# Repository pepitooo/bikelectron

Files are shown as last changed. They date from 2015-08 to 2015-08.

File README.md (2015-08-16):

# BikElectron
Personnal project to illumate rim on a bike during night, "Tron" effect

## Why this project ?
To be simple, I was not satisfy with the common lightning system. I saw on kickstarter some project with led around the rim, but it had too much constraints and it was so visible during day. Then the idea : using "glow in the dark" stickers.

## First prototype
The [first prototype](https://github.com/pepitooo/OpenSCAD_leds_support) was not too bad, using a flashlight from DX.com or AliExpress and some glow in the dark tape.

I was not so happy with the size of each led support and fix system was not good at all.

# Project parts

## Electronic
It's so basic, 2 times a resitor and a UV/blacklight led in parallel.
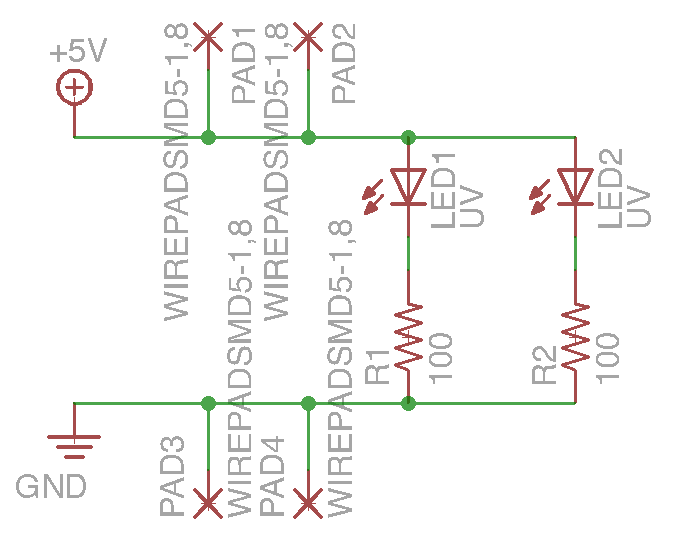
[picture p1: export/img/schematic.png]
Eagle shematic Screenshot


## PCB
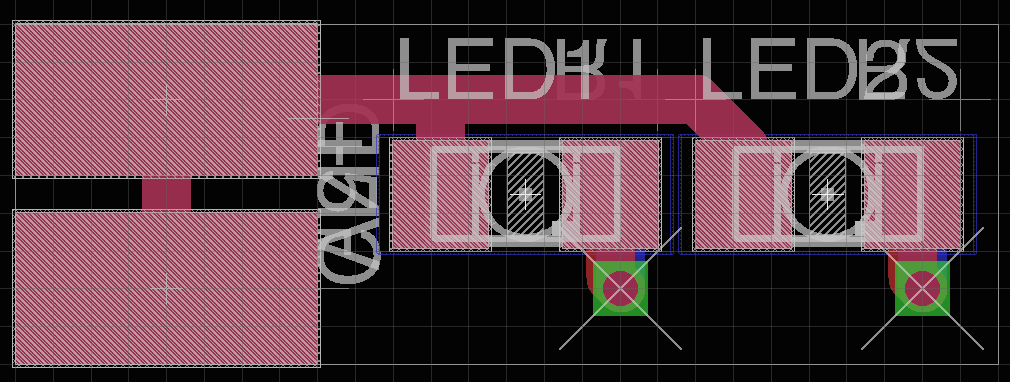
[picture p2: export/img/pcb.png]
Eagle PCB Screenshot


## Battery pack
I took a battery pack used to charge phone, it's cheap, and powerfull enough.
I used a USB cable for wiring all modules togeter.

## Case 3D printed
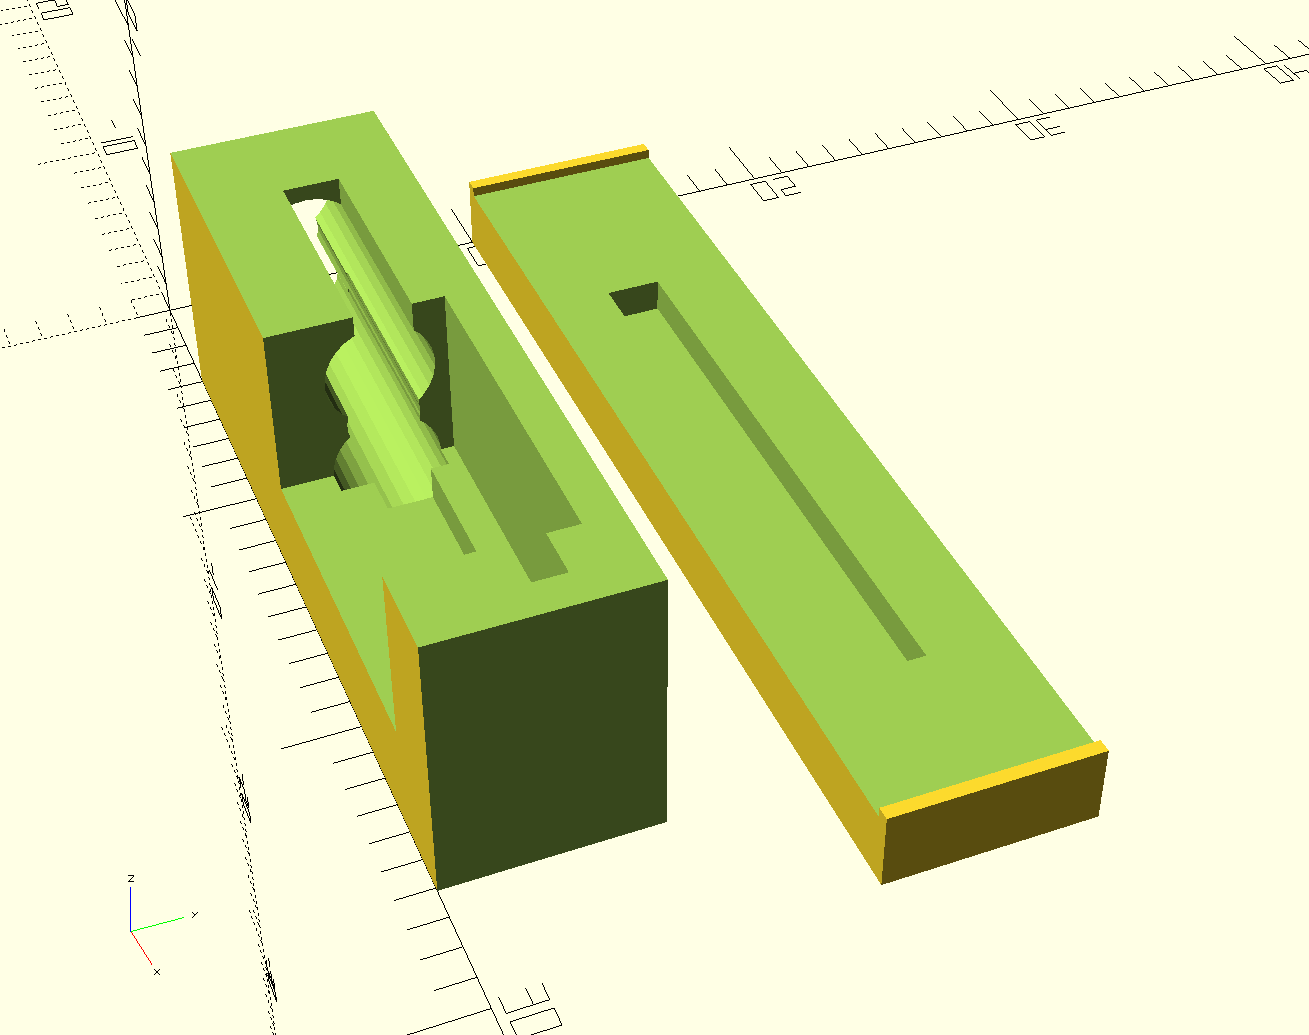
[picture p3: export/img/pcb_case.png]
Case Screenshot


## Stickers
I used glow in the dark vinyl warp and lazer cut it. If you are precise enough cisor can do the job.
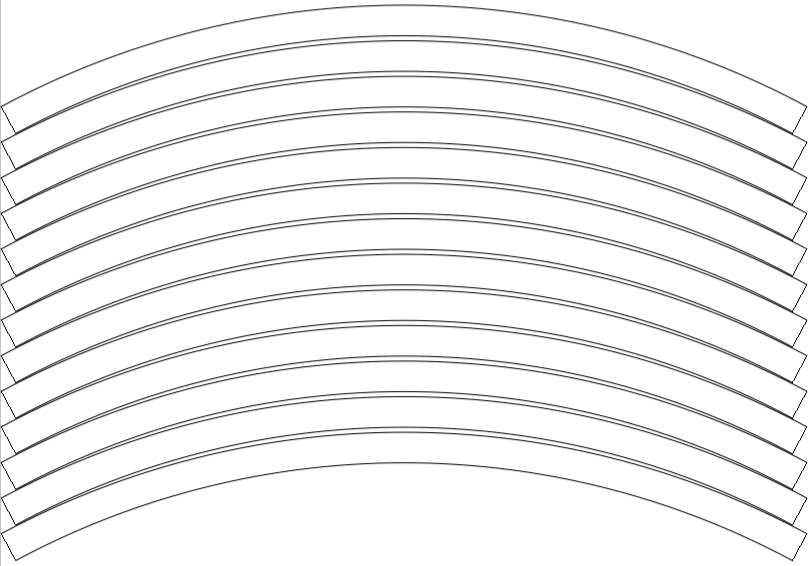
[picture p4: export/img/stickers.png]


## All elements together
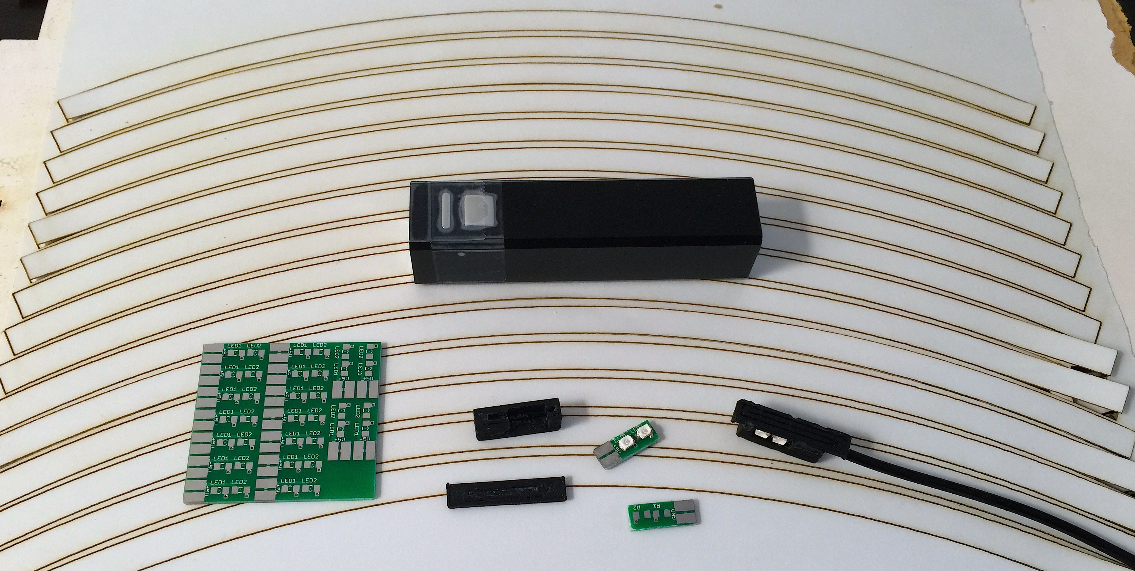
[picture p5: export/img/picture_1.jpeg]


# Final product
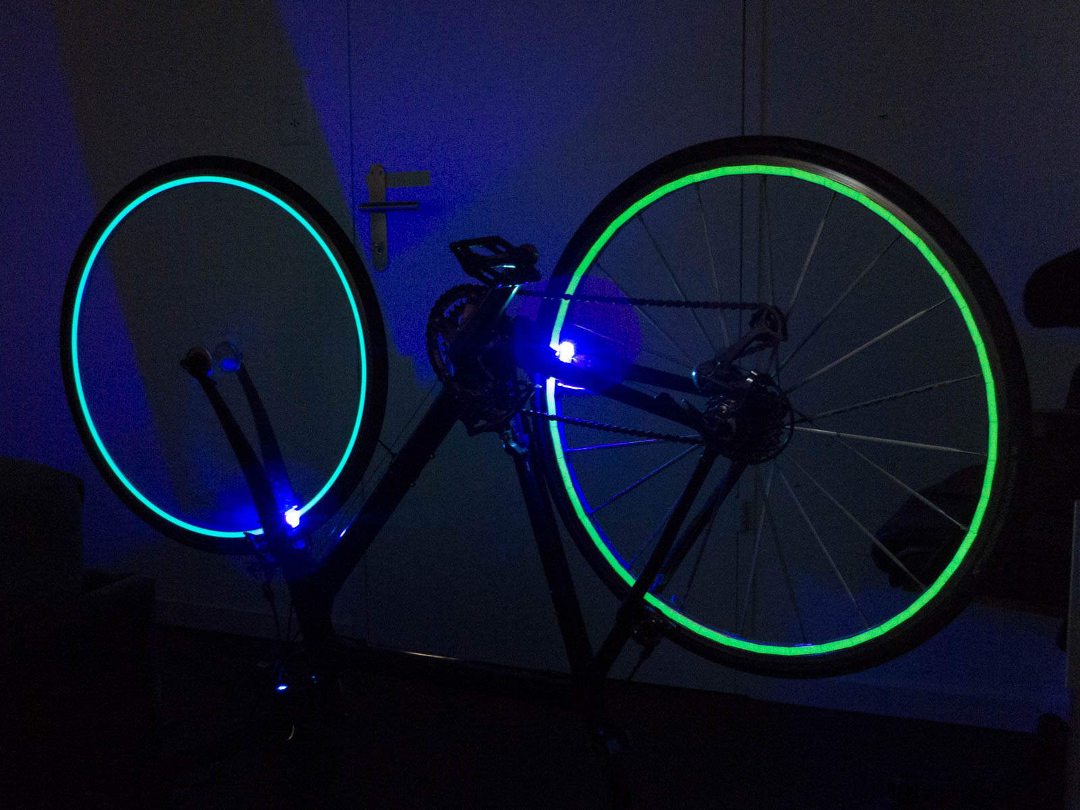
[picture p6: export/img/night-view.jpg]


You need to sold in serial 2 led module for each wheel using the USB cable.
On the picture of the final product the front wheel is more blue than rear, it's because I bought some blue glow in the dark tape. 

I used the stickers lazer cut for the front wheel, and for the rear wheel it's from the [first prototype](https://github.com/pepitooo/OpenSCAD_leds_support) where I used 10mm tape, and cut in a lot of small piece to cover all the rim.

If you want to do the same, take a good quality glow in the dark viny to have a shiny light. The chinese seller use hour of light after illumination as "quality" take one with at least 12 hours.

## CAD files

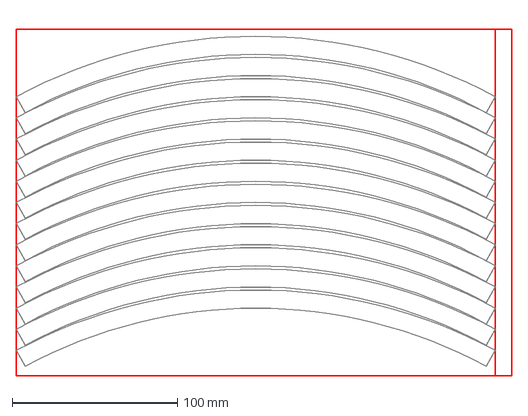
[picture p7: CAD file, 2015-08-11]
cad/stickers/stickers_rim_700c.dxf
300.0 x 217.9 mm

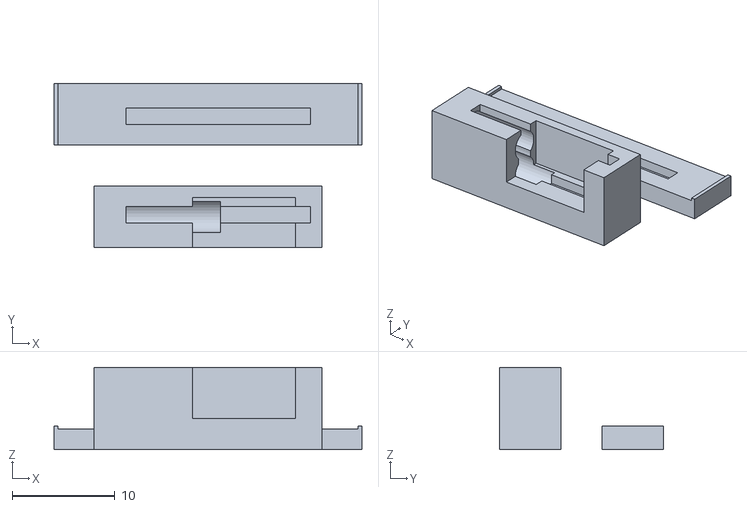
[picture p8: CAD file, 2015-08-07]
export/stl/leds_support_for_pcb_right.stl
30.0 x 16.0 x 7.99

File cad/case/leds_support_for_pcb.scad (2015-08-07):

$fn=30;

pcb_thickness=1.6;
pcb_length=18;

top_block=[30,6,10];

wire_hole_diameter=3.05;

handle_size = 4;

module resistor_1206(){
  color([1,0,0.5])
    cube([3, 0.5, 1.5], 0);
}
module led_3528(){
  color([0,0,0.5])
    translate([0, -1.9, 0])
      cube([4.5, 1.9, 2.8], 0);
}

module pcb(thickness) {
  color([0,1,0.5])
    cube([pcb_length, thickness, 7], 0);
  
  //translate([7, thickness, 3]) resistor_1206();
  //translate([12, thickness, 3]) resistor_1206();
  //translate([6.3, 0, 2]) led_3528();
  //translate([11.3, 0, 2]) led_3528();
}

module handle() {
  color([1,0.7,0.5])
    translate([30/2 - handle_size + 0.1,-0.5,0]) {
      difference() {
        cube([handle_size, 9, 10]);
        translate([3.5, 0, 0])
          cube([.5,9,.3]);
      }
    }
}

module wire_pass_through(diameter) {
  //rotate([90,270,90])
  translate([16.1,0,1])
  rotate([0,270,0]) {
    //difference() {
    //  cube([9,6,3]);
      translate([3,3,-.1])
        cylinder(h = 17, d=diameter);
      translate([6,3,-.1])
        cylinder(h = 17, d=diameter);
      translate([4.5,3,-.1])
        cylinder(h = 17, d=diameter-1);
    }
}

module led_window(leftSideWindows = false) {
  color([1,0.7,0.5])
    if(leftSideWindows) {
      translate([12.5,-.1,2])
          cube([10,5,5]);
    } else {
      translate([13.5,1.1,2])
          cube([10,5,5]);
    }
}

module case(leftSideWindows = false) {  
  difference() {
    cube(top_block);
    led_window(leftSideWindows);
    wire_pass_through(wire_hole_diameter);
    translate([7,2,1]) pcb(pcb_thickness);
    translate([30 / 2, 0, 2]) {
      handle();
      mirror([1,0,0]) handle();
    }
  }
}

module slide_case(leftSideWindows) {
  //bottom part
  translate([0,10,0])
  difference() {
    case(leftSideWindows);
    translate([3,-0.5,2]) cube([25,7,11]);
  }  
  
  rotate([180,0,0])
    translate([0,-6,-10])
  difference() {
    case(leftSideWindows);
    translate([-.5,-0.5,-8.99]) cube([31,7,11]);
    translate([-.5,-0.5,]) cube([3,7,3]);
    translate([28,-0.5,]) cube([3,7,3]);
  }
}

slide_case(false);

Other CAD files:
export/stl/leds_support_for_pcb_left.stl
export/stl/leds_support_for_pcb.stl

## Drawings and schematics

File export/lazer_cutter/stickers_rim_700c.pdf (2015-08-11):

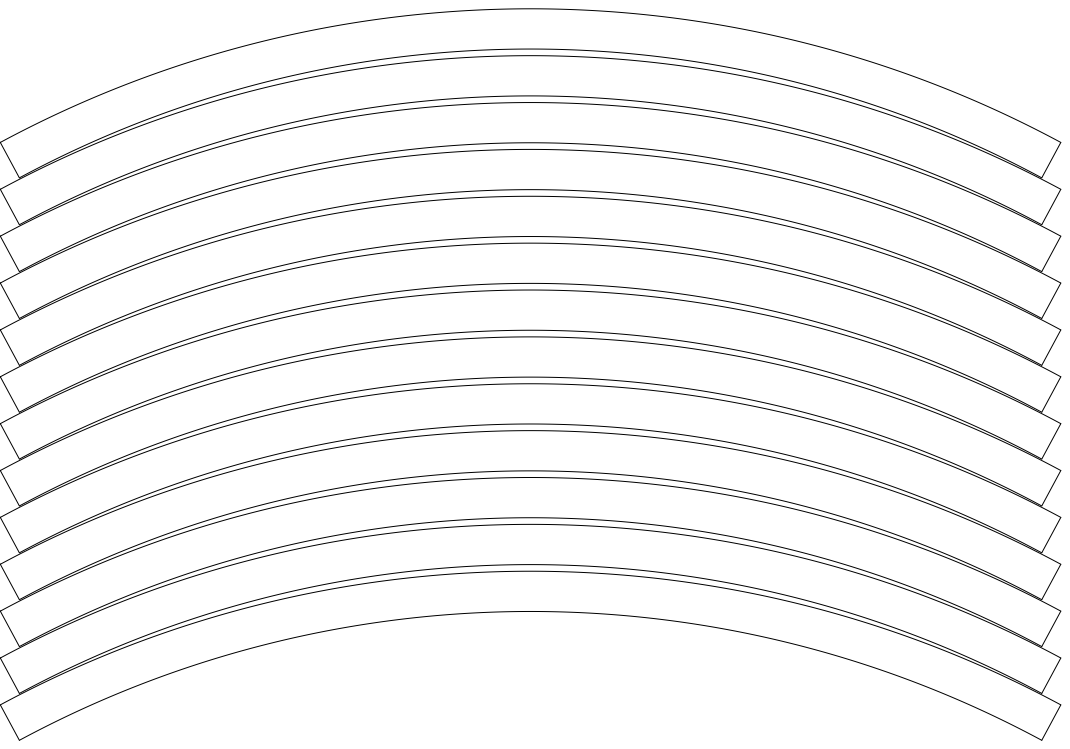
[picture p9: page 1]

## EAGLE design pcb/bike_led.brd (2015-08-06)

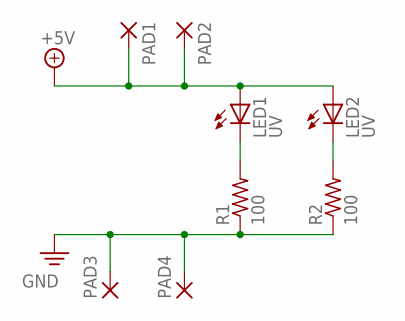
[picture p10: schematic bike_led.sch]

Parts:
LED1, LED2: UV; 1206
PAD1, PAD2, PAD3, PAD4: SMD5; SMD2,54-5,08
R1, R2: 100; R1206

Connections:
+5V: LED1.A, LED2.A, PAD1.1, PAD2.1
GND: PAD3.1, PAD4.1, R1.1, R2.1
unnamed: LED2.C, R2.2
unnamed: LED1.C, R1.2

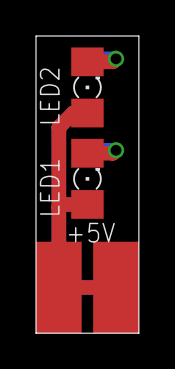
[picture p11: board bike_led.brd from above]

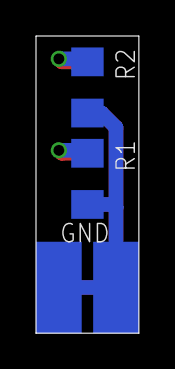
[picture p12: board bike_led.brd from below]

Board: 2 copper layers, 5.7 x 16.5 mm, 8 parts (4 on the bottom side), 4 nets.

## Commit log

2015-08-06 group all part of the project in a repo
    [bike_led.brd, bike_led.sch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]
2015-08-06 sticker cad for being cut by a lazer at FabLab Zurich
    [stickers_rim_700c.dxf]
2015-08-06 New picture added with all parts, pcb, 3d printed case, cutted stickers, battery pack
2015-08-07 change led windows side using a boolean
    [leds_support_for_pcb.scad, leds_support_for_pcb_left.stl, leds_support_for_pcb_right.stl]
2015-08-11 enlarge sticker width to 11mm
    [stickers_rim_700c.dxf]
2015-08-11 add a new layer with 4 points to position correctly the paper
    [stickers_rim_700c.dxf]
2015-08-16 Schematic of PCB
